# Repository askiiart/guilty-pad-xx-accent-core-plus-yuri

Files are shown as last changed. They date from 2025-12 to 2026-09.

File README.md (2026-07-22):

# Guilty Pad XX Λ Core Plus R

This is a pretty simple TKL keyboard with backlighting, an OLED, and a rotary encoder. The fancy trick is that it's designed to work with the [GUILTY PAD -GAY-](https://github.com/askiiart/guilty-pad-gay), so you can do whatever you want with it via Bluetooth. Connect them together and use the hackpad as macro key combos or something, literally anything!

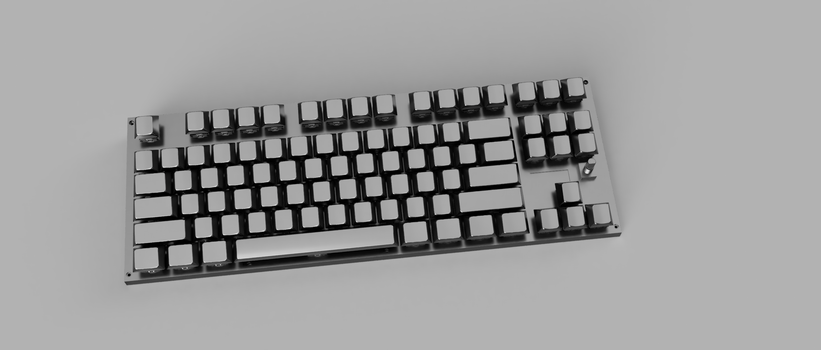
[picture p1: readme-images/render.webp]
A render of the board looking straight-ish at it


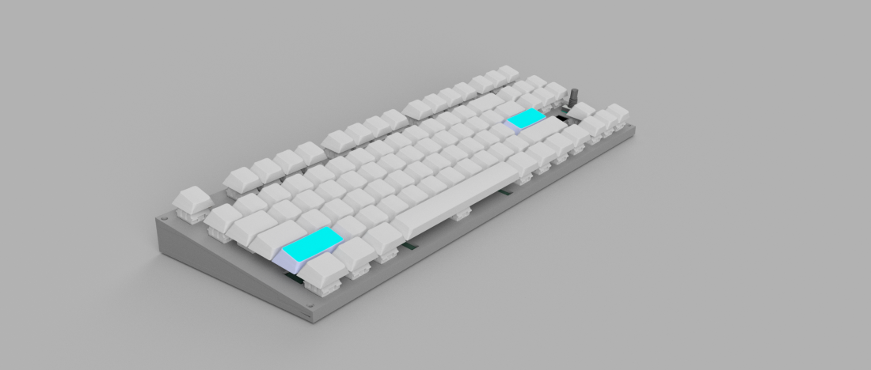
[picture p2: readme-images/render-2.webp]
A render of the board looking at it at a roughly 45 degree angle from the front-left-top side


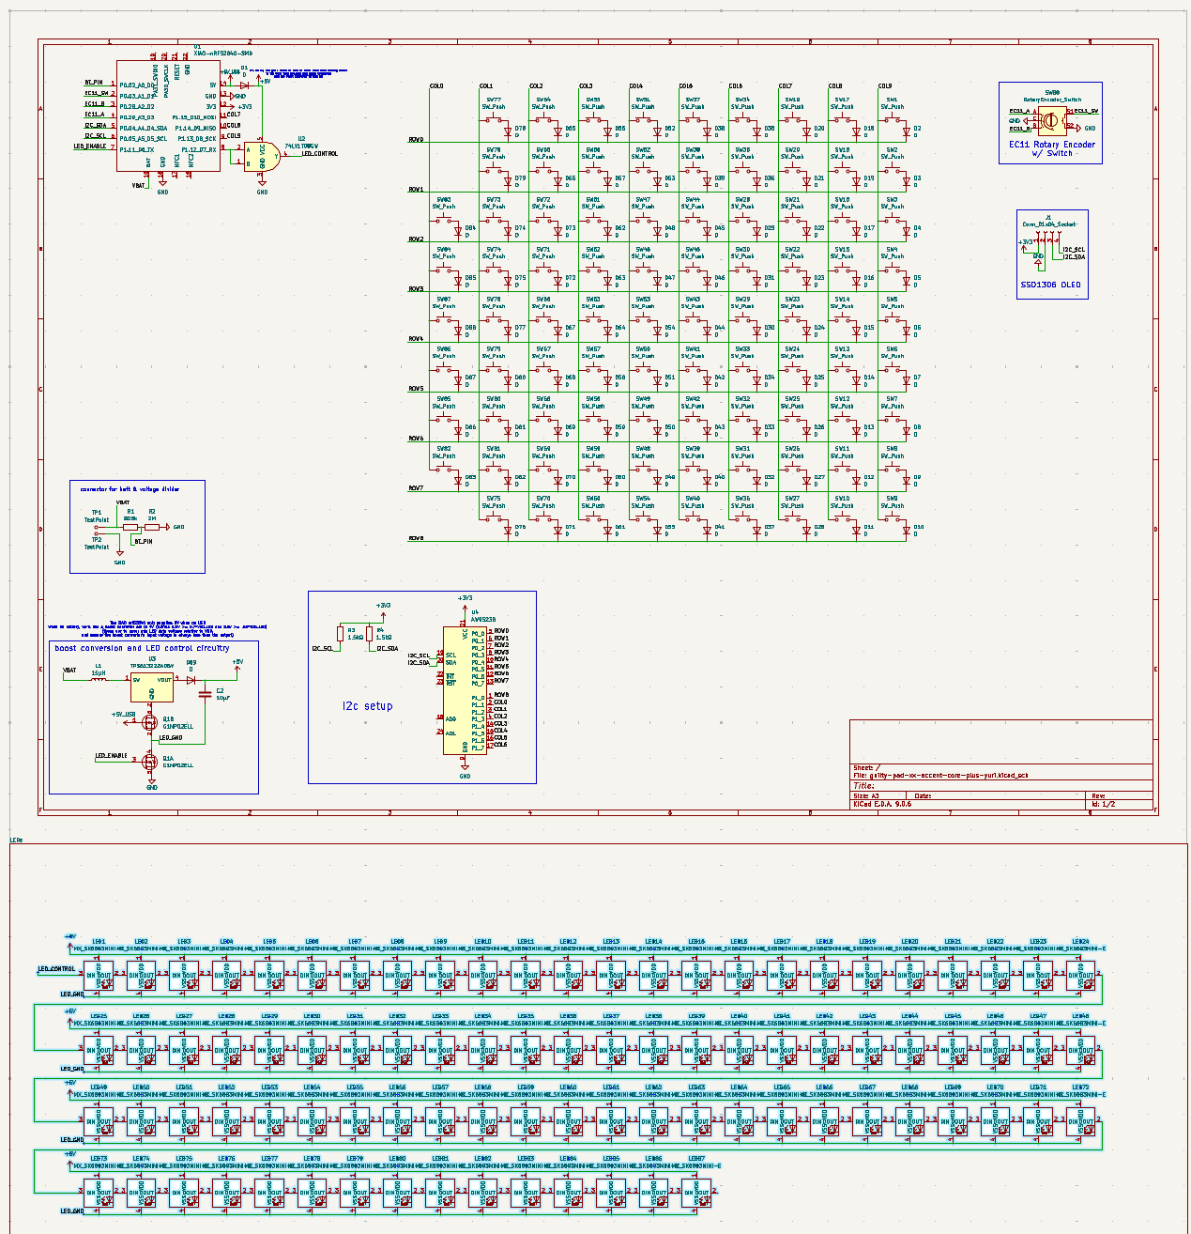
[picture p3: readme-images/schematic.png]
A screenshot of the schematic


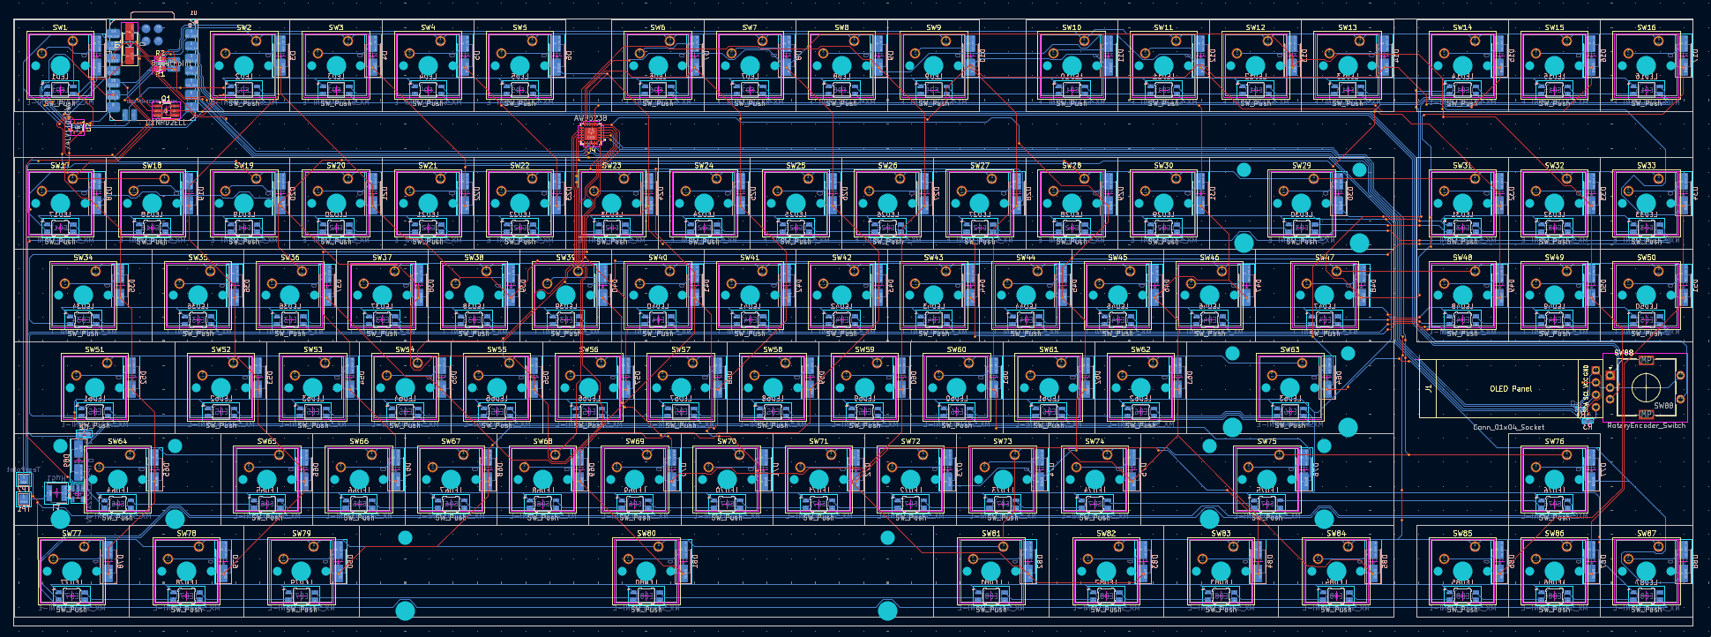
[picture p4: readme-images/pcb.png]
A screenshot of the PCB


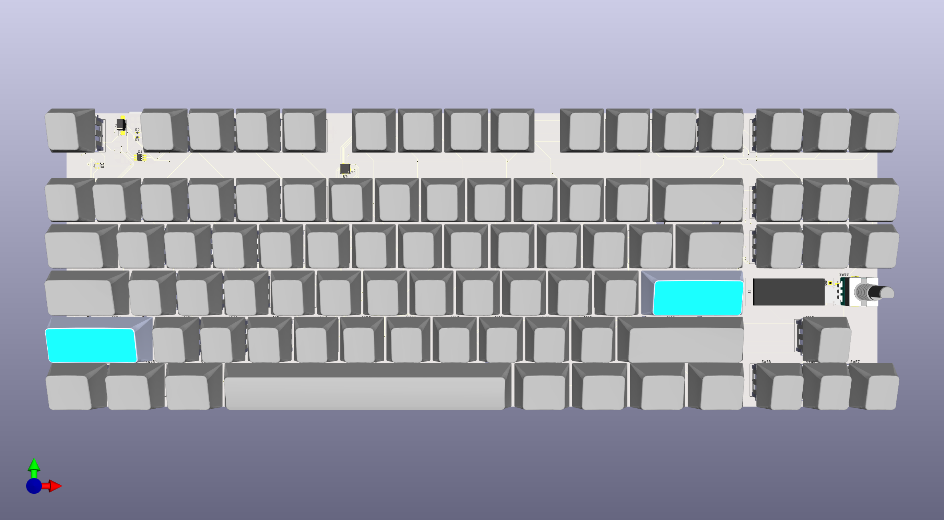
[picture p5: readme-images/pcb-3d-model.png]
A screenshot of the 3D rendering of the PCB with all components


---

The woke left made me add yuri (I actually haven't added any yet, busy doing actually useful stuff)

## Bill of Materials

| Name | Link | Unit price | Quantity needed | MOQ | Multiple | Total per item |
| --- | --- | --- | --- | --- | --- | --- |
| XIAO nrf52840 | <https://www.seeedstudio.com/Seeed-XIAO-BLE-nRF52840-p-5201.html> | 8.99 | 1 | 1 | 1 | 8.99 |
| 0402 4.7k resistors (GR0402J4K7TAG00) | <https://www.lcsc.com/product-detail/C49656853.html> | 0 | 2 | 100 | 100 | 0.04 |
| Rotary encoder w/ switch (EC11E18244A5) | <https://www.lcsc.com/product-detail/C255515.html> | 2.05 | 1 | 1 | 1 | 2.05 |
| 0402 806k resistor (SCR0402F806K) | <https://www.lcsc.com/product-detail/C3016043.html> | 0 | 1 | 100 | 100 | 0.05 |
| 0402 2M resistor (GR0402J2MTAG00) | <https://www.lcsc.com/product-detail/C49653113.html> | 0 | 1 | 100 | 100 | 0.04 |
| 0603 10uF capacitor (CL10A106MQ8NNNC) | <https://www.lcsc.com/product-detail/C1691.html> | 0 | 1 | 50  | 50 | 0.24 |
| 60x Mill-Max hotswap sockets | <https://keeb.io/products/mill-max-hotswap-sockets?variant=32377167511646> | 7.99 | 3 | 1 | 1 | 23.97 |
| 20x SK6803MINI-E (LEDs) | <https://www.aliexpress.us/item/3256807898532204.html> | 31.16 | 5 | 1 | 1 | 24.7 |
| 22 AWG wires w/ JST XH connectors | <https://www.aliexpress.us/item/3256803495901819.html> | 0.99 | 1 | 1 | 1 | 0.99 |
| Complimentary P/N channel MOSFETs (G1NP02ELL) | <https://www.lcsc.com/product-detail/C840056.html> | 0.03 | 1 | 20  | 20 | 0.66 |
| 15 uH Inductor (SLW4030S150MST) | <https://www.lcsc.com/product-detail/C206361.html> | 0.07 | 1 | 10  | 10 | 0.69 |
| 5V boost converter (H8118A40PR) | <https://www.lcsc.com/product-detail/C410998.html> | 0.13 | 1 | 5 | 5 | 0.66 |
| Diodes (1N4001) | <https://www.lcsc.com/product-detail/C2909965.html> | 0 | 89 | 50  | 50 | 0.41 |
| Level shifter (74LV1T08GW-TP) | <https://www.lcsc.com/product-detail/C42460230.html> | 0.06 | 1 | 10  | 10 | 0.57 |
| 90x MX switches (Holy Panda 55g) | <https://www.aliexpress.us/item/3256805924985540.html> | 5.49 | 1 | 1 | 1 | 5.49 |
| IO expander (AW9523BTQR) | <https://www.lcsc.com/product-detail/C148077.html> | 0.35 | 1 | 1 | 1 | 0.35 |
| Keycaps | <https://www.aliexpress.us/item/3256809006592332.html> | 0.99 | 1 | 1 | 1 | 0.99 |
| 5000mAh 307090 lipo | <https://www.aliexpress.us/item/3256809787664995.html> | $5.18 | 1 | 1 | 1 | 4.18 |
| M2 screws and heat-set inserts (10x M2x3 inserts, 6x M2x4 (5?), 4x M2xTBD) | <https://www.aliexpress.us/item/3256807644176828.html> | 0.99 | 1 | 1 | 0.99 | 0.99 |
| 0.91" 128x32 OLED | <https://www.aliexpress.us/item/3256804386173217.html> | 0.99 | 1 | 1 | 0.99 | 0.99 |
| | | | | | | |
| Component Total | | | | | | 78.05 |
| | | | | | | |
| PCB total | | | | | | 29.74 |
| Seeed studio shipping | | | | | | 5.46 |
| keeb.io shipping | | | | | | 6.37 |
| SK6803MINI-E shipping | | | | | | 6.52 |
| 5000mAh lipo shipping | | | | | | 5.41 |
| LCSC shipping & handling | | | | | | 11.71 |
| | | | | | | |
| Subtotal | | | | | | 143.25 |
| Without mill-max sockets | | | | | | 112.91 |
| | | | | | | |
| Total | | | | | | 155.07 |
| **Without mill-max sockets** | | | | | | 122.23 |

## TODO

- redo routing everything
- [crystal](https://www.lcsc.com/product-detail/C18213028.html)
  - [capacitors](https://www.lcsc.com/product-detail/C501818.html)
- [antenna](https://www.lcsc.com/product-detail/C42395593.html)
- [usb resistors](https://www.lcsc.com/product-detail/C2906874.html)
- battery management chip: [SGM40567](https://www.lcsc.com/product-detail/C5141336.html)
  - [digipot for PROG](https://www.lcsc.com/product-detail/C649485.html)
- [usb-c port](https://jlcpcb.com/partdetail/Korean_HropartsElec-TYPE_C_31_M12/C165948)
- reset button
  - [reset button?](https://www.aliexpress.us/item/3256806601702089.html)
  - [reset buttonnnnnn?](https://www.lcsc.com/product-detail/C49234121.html)
- [pmos for voltage regulators](https://www.lcsc.com/product-detail/C239037.html)
- [D4 (3A)](https://www.lcsc.com/product-detail/C97127.html)
- [D1, D2, D3, D7 (1A)](https://www.lcsc.com/product-detail/C2912031.html)
- [D5, D6 (2A)](https://www.lcsc.com/product-detail/C153761.html)
- [5V boost converter](https://www.lcsc.com/product-detail/C621881.html)

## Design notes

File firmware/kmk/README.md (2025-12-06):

Just basic firmware to get it working, not doing anything fancy since I can't test currently

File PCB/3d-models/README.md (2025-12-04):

# 3d model sources

- [XIAO nrf52840](https://www.printables.com/model/1336692-3d-model-for-seeed-studio-xiao-nrf52840)
- [SK6812MINI-E](https://grabcad.com/library/sk6812mini-e-led-1)
- [OLED](https://github.com/MichMich/KiCad-SSD1306_OLED-0.91-128x32)
- [Kailh MX switch](https://grabcad.com/library/kailh-polia-switch-cherry-mx-compatible-1)
- [IO Expander](https://kicad.github.io/packages3d/Package_DFN_QFN.html)
- [Level shifter](https://kicad.github.io/download/packages3d/Package_TO_SOT_SMD.3dshapes.7z)
- [EC11 rotary encoder](https://grabcad.com/library/rotary-encoder-17)
- [keycaps](hthttps://github.com/hineybush/CherryMX)

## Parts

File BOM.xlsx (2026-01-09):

Name | Link | Unit price | Quantity needed | MOQ | Multiple | Quantity to order | Total per item
XIAO nRF52840 | https://www.seeedstudio.com/Seeed-XIAO-BLE-nRF52840-p-5201.html | 8.99 | 1 | 1 | 1 | 1 | 8.99
0402 4.7k resistors (GR0402J4K7TAG00) | https://www.lcsc.com/product-detail/C49656853.html | 0.0004 | 2 | 100 | 100 | 100 | 0.04
Rotary encoder w/ switch (EC11E18244A5) | https://www.lcsc.com/product-detail/C255515.html | 2.05 | 1 | 1 | 1 | 1 | 2.05
0402 806k resistor (SCR0402F806K) | https://www.lcsc.com/product-detail/C3016043.html | 0.0005 | 1 | 100 | 100 | 100 | 0.05
0402 2M resistor (GR0402J2MTAG00) | https://www.lcsc.com/product-detail/C49653113.html | 0.0004 | 1 | 100 | 100 | 100 | 0.04
0603 10uF capacitor (CL10A106MQ8NNNC) | https://www.lcsc.com/product-detail/C1691.html | 0.0048 | 1 | 50 | 50 | 50 | 0.24
Gateron/Outemu 90x hotswap sockets | https://www.aliexpress.com/item/3256802450835694.html?mp=1 | 0.99 | 1 | 1 | 1 | 1 | 0.99
LEDs (SK6803MINI-E) | https://www.lcsc.com/product-detail/C5242955.html | 0.0656 | 90 | 5 | 5 | 90 | 5.904
22 AWG wires w/ JST XH connectors | https://www.aliexpress.us/item/3256803495901819.html | 0.99 | 1 | 1 | 1 | 1 | 0.99
Complimentary P/N channel MOSFETs (G1NP02ELL) | https://www.lcsc.com/product-detail/C840056.html | 0.0332 | 1 | 20 | 20 | 20 | 0.664
15 uH Inductor (SLW4030S150MST) | https://www.lcsc.com/product-detail/C206361.html | 0.039 | 1 | 10 | 10 | 10 | 0.39
5V boost converter (TPS613222ADBVR) | https://www.lcsc.com/product-detail/C2071163.html | 0.1487 | 1 | 5 | 5 | 5 | 0.7435
Diodes (1N4148) | https://www.lcsc.com/product-detail/C2904852.html?s_z=n_1n4148 | 0.004 | 89 | 100 | 100 | 100 | 0.4
Level shifter (74LV1T08GW-TP) | https://www.lcsc.com/product-detail/C42460230.html | 0.057 | 2 | 10 | 10 | 10 | 0.57
MX switches | Any | 0 | 87 | 1 | 1 | 87 | 0
IO expander (PCA9555PW) | https://www.lcsc.com/product-detail/C42420607.html | 0.2831 | 1 | 1 | 1 | 1 | 0.2831
Keycaps | https://www.aliexpress.com/item/3256807135386098.html?mp=1 | 7.88 | 1 | 1 | 1 | 1 | 7.88
5000mAh lipo | https://www.aliexpress.com/item/3256808773650739.html?mp=1 | 8.03 | 1 | 1 | 1 | 1 | 8.03
M2 screws and heat-set inserts (10x M2x3 inserts, 6x M2x4 (5?), 4x M2xTBD) | https://www.aliexpress.us/item/3256807644176828.html | 5.09 | 1 | 1 | 1 | 1 | 5.09
0.91" 128x32 OLED | https://www.aliexpress.us/item/3256804386173217.html | 2.02 | 1 | 1 | 1 | 1 | 2.02
Component Total |  |  |  |  |  |  | 45.3646
PCB total |  |  |  |  |  |  | 39.13
Seeed studio shipping |  |  |  |  |  |  | 5.46
5000mAh lipo shipping |  |  |  |  |  |  | 5.43
LCSC shipping & handling |  |  |  |  |  |  | 11.71
Subtotal |  |  |  |  |  |  | 107.0946
Total |  |  |  |  |  |  | 115.9299045

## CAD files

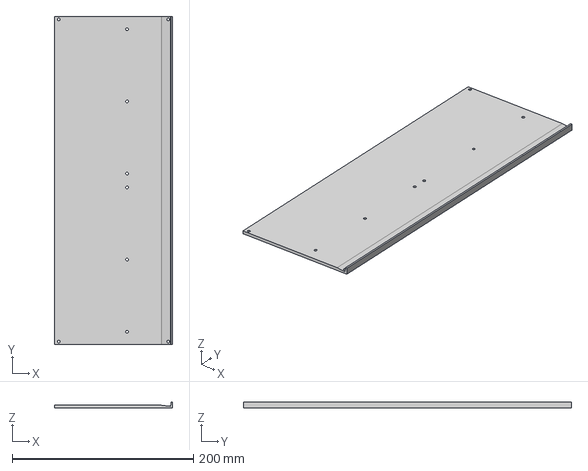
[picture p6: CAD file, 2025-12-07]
CAD/case-bottom.step
130.5 x 362.2 x 6.95 mm

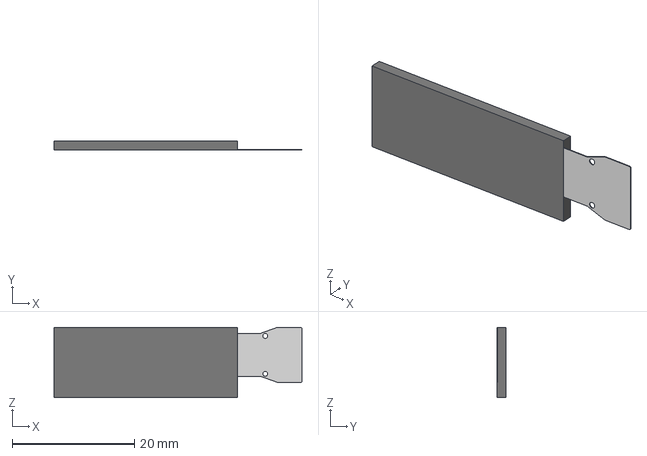
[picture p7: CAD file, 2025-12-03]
PCB/3d-models/SSD1306_OLED-0.91-128x32.step
40.5 x 1.45 x 11.5 mm

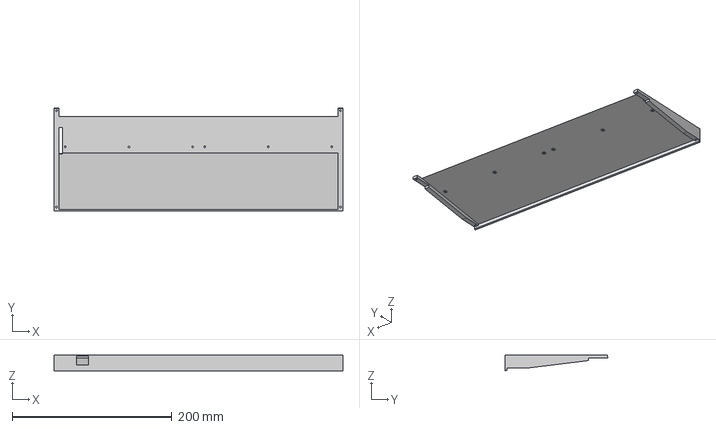
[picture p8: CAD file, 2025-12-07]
CAD/case-middle.step
362.2 x 128.9 x 19.6 mm

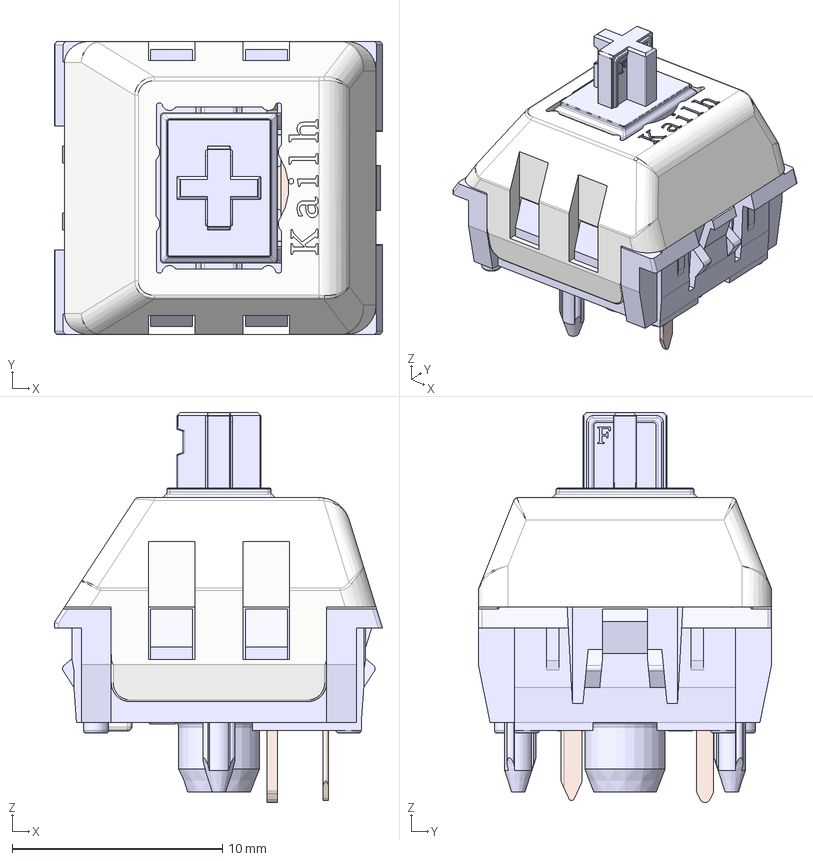
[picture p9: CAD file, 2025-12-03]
PCB/3d-models/Kailh Polia.step
15.6 x 14.0 x 18.5 mm
Housing
ThickContact
SpringContact
Stem
Lid

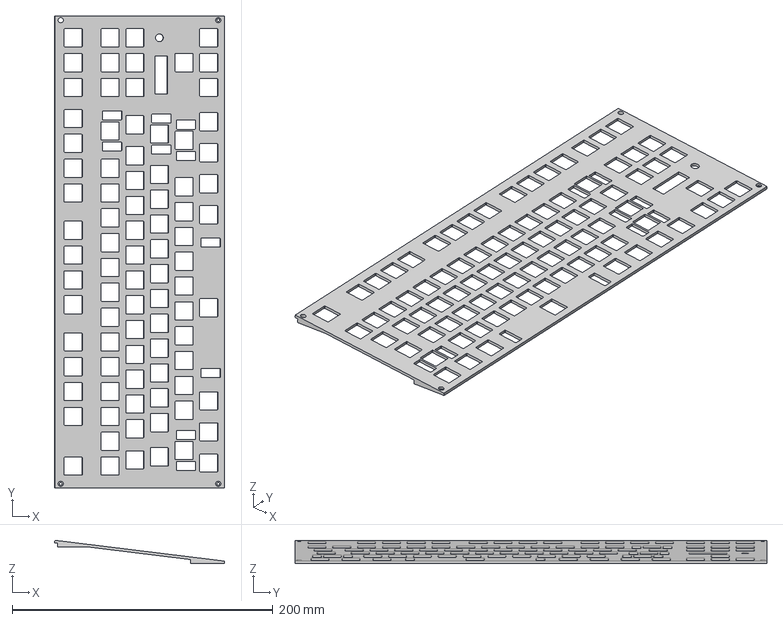
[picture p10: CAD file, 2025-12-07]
CAD/case-top.step
130.5 x 362.2 x 18.0 mm

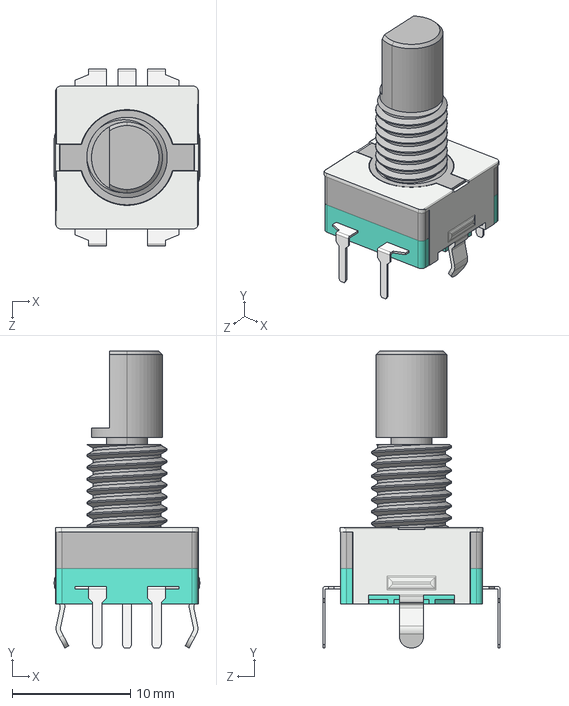
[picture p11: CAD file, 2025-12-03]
PCB/3d-models/ec11.step
12.3 x 25.1 x 15.0 mm

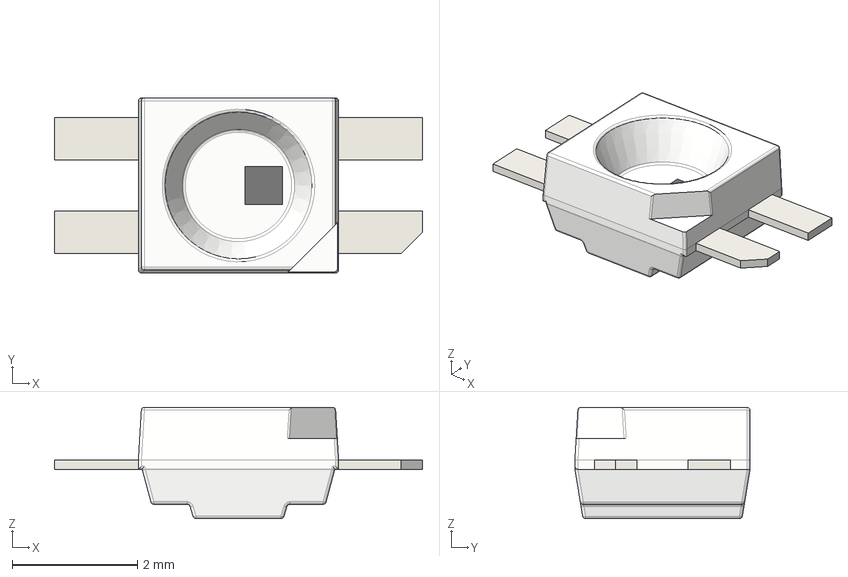
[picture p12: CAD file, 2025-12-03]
PCB/3d-models/LED_SK6812MINI-E.step
5.88 x 2.80 x 1.78 mm

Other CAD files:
CAD/case-bottom.f3d
CAD/case-middle.f3d
CAD/case-top.f3d

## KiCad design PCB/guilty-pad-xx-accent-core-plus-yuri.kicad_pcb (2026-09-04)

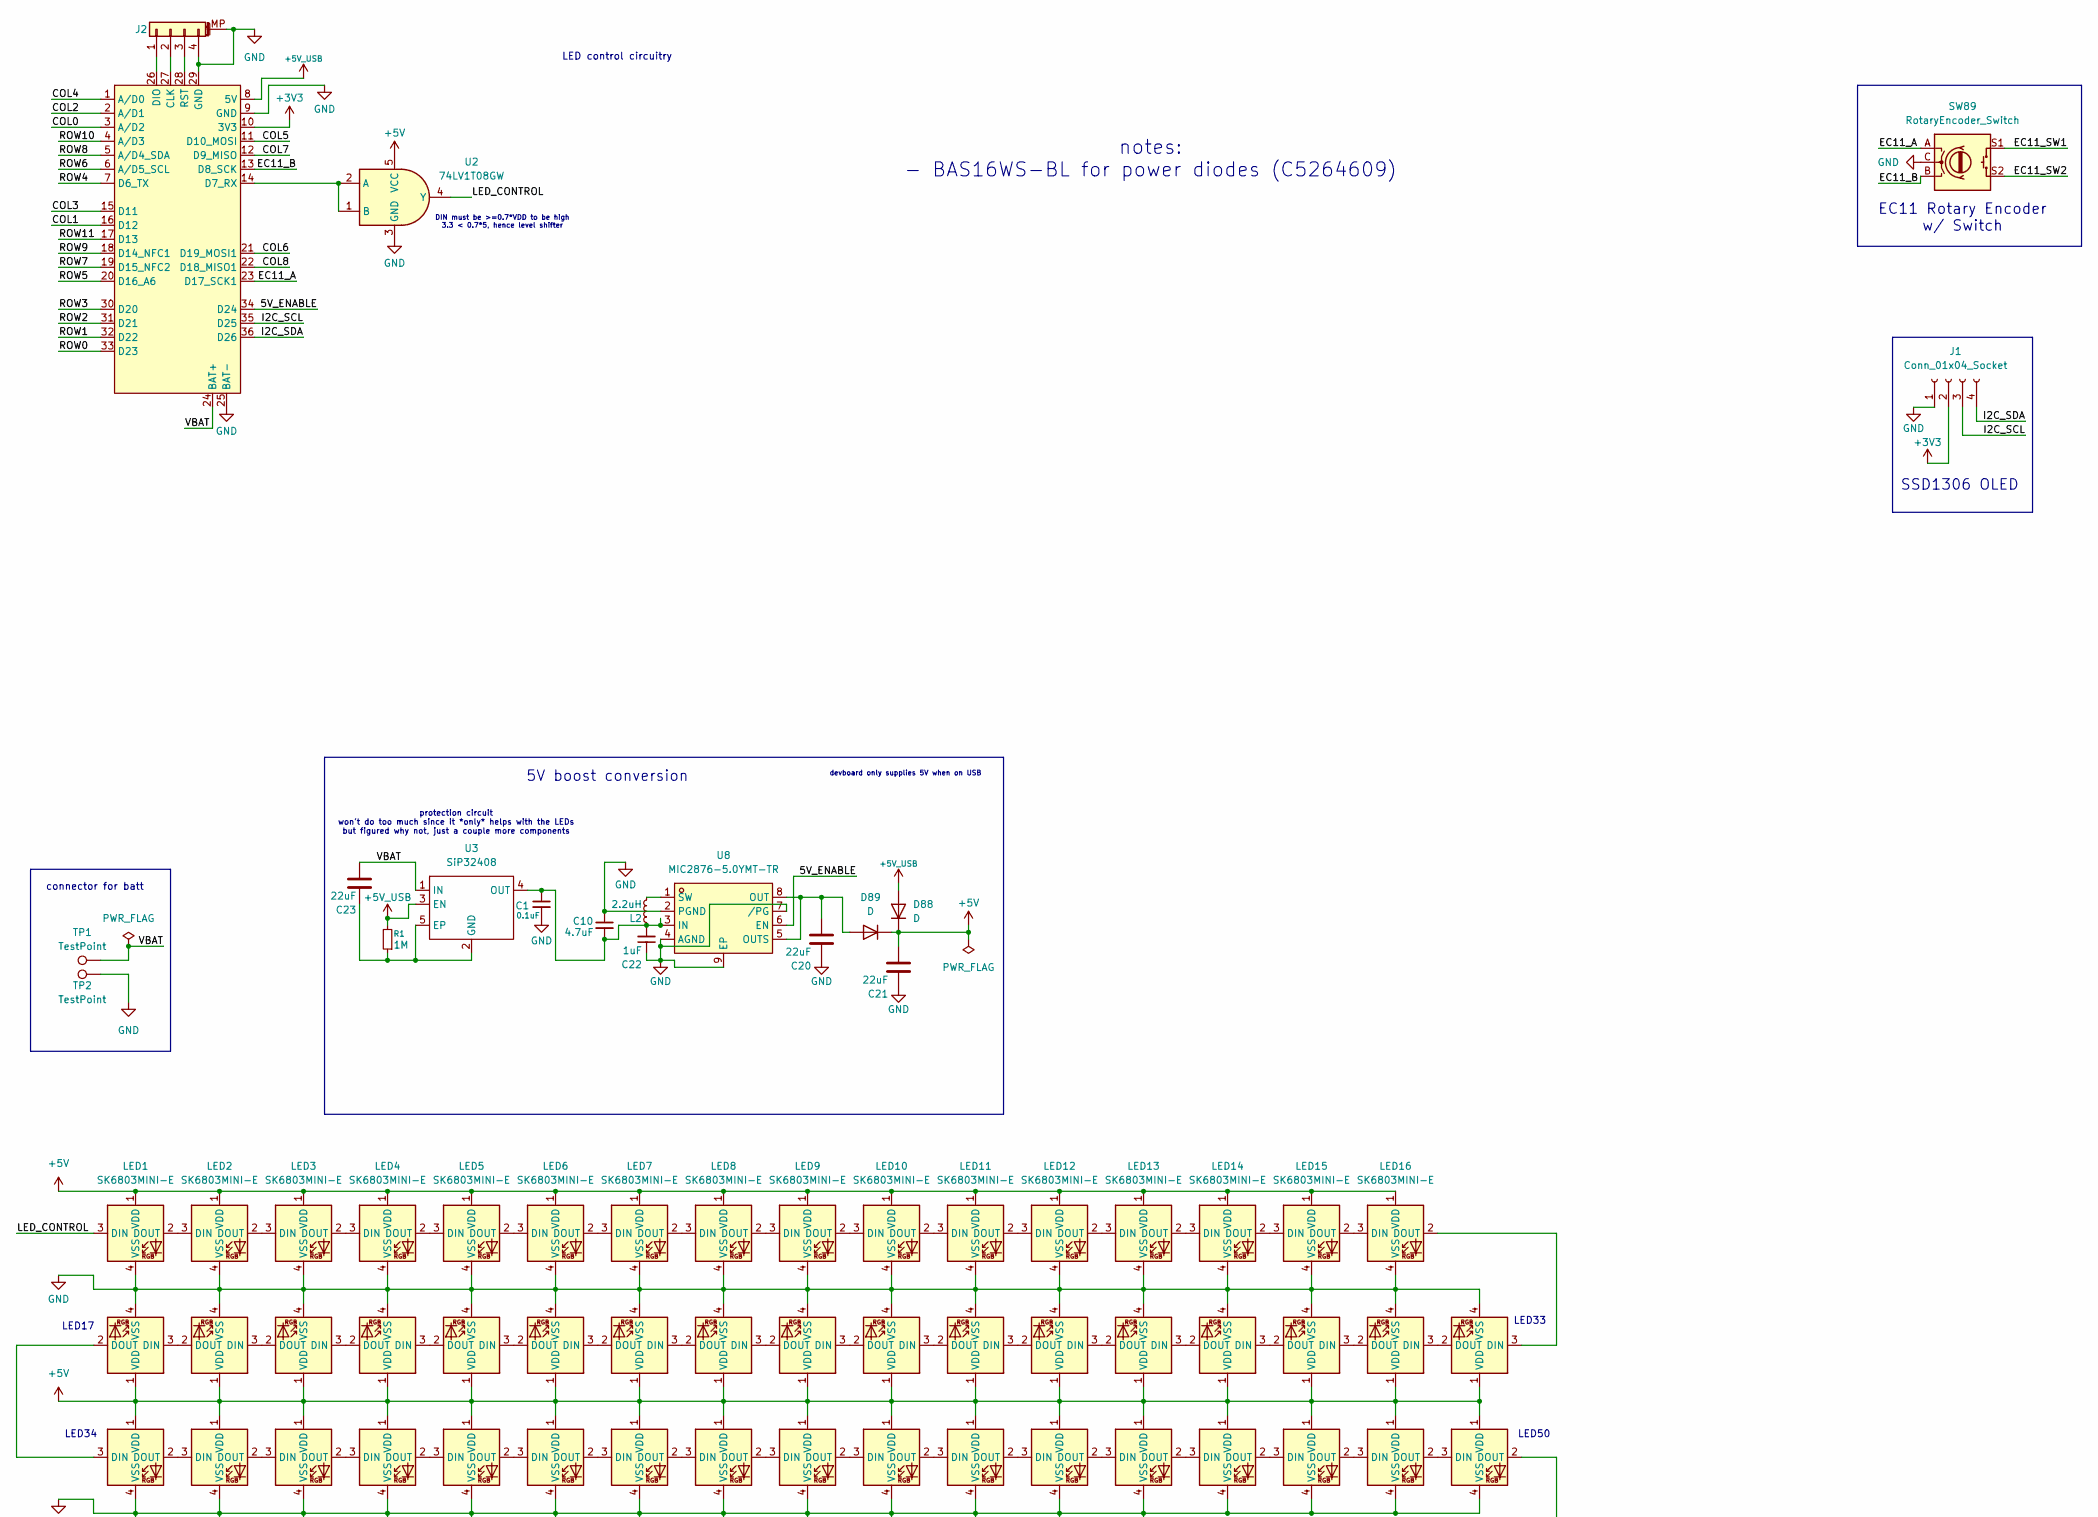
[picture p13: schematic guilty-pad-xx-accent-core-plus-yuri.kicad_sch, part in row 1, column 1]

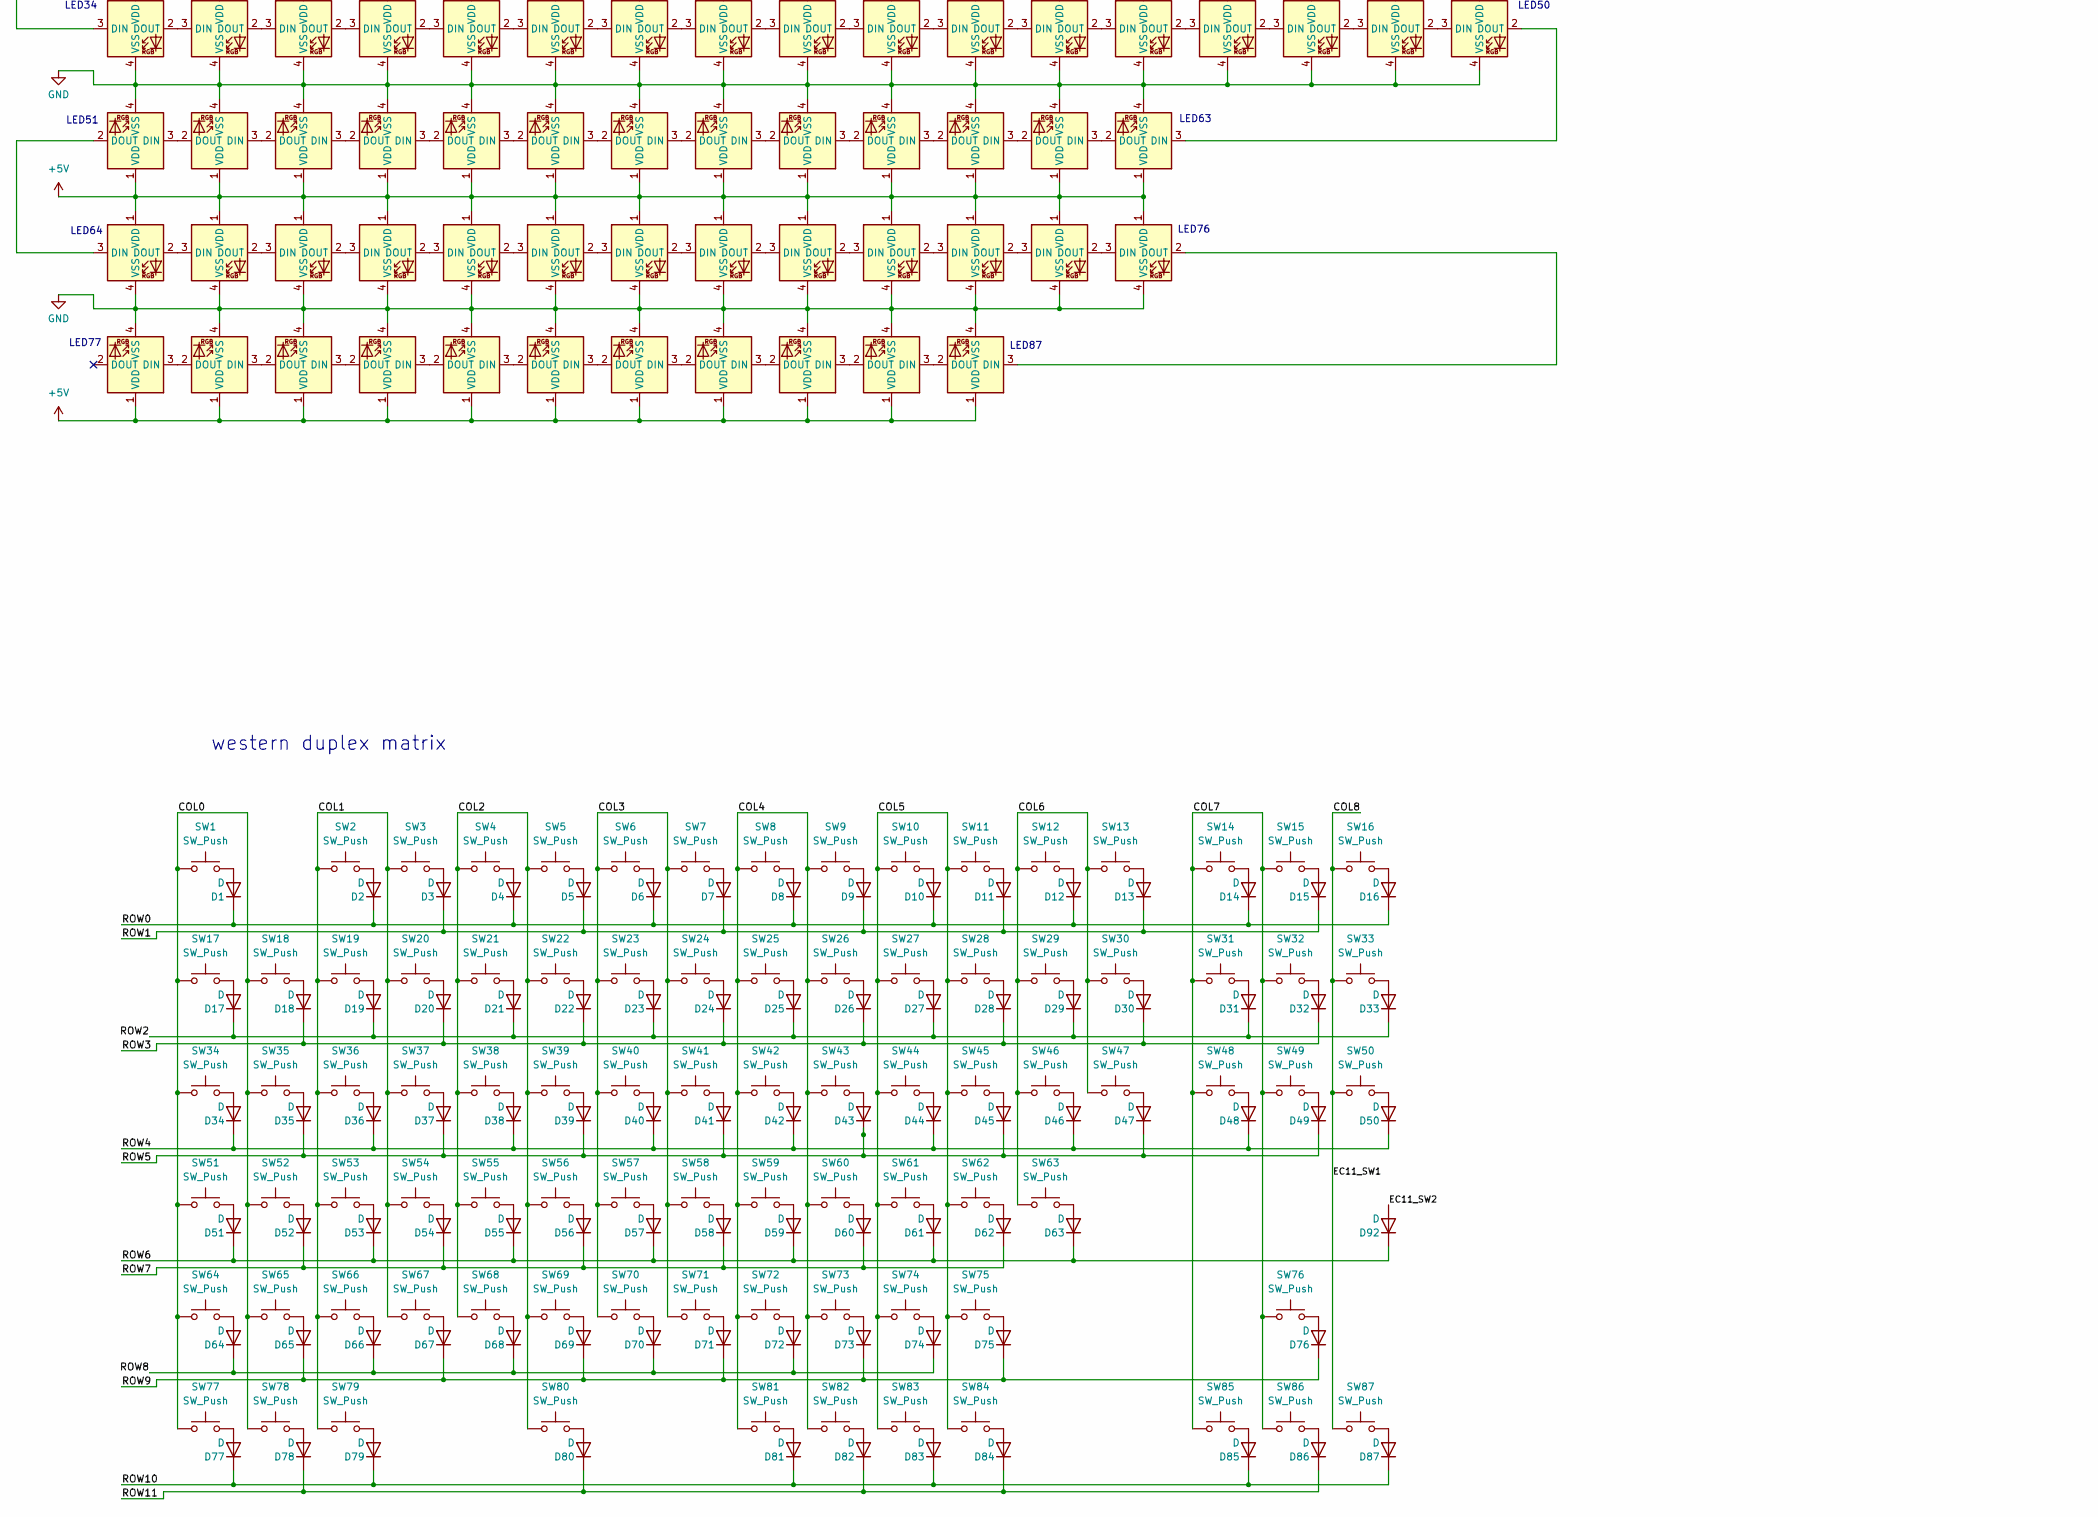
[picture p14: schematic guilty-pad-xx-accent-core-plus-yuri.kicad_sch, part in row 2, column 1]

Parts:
C1: 0.1uF; C_0603_1608Metric
C10: 4.7uF; C_0603_1608Metric
C20, C21, C23: 22uF; C_0603_1608Metric
C22: 1uF; C_0603_1608Metric
D1, D2, D3, D4, D5, D6, D7, D8, D9, D10, D11, D12, D13, D14, D15, D16, D17, D18, D19, D20, D21, D22, D23, D24, D25, D26, D27, D28, D29, D30, D31, D32, D33, D34, D35, D36, D37, D38, D39, D40, D41, D42, D43, D44, D45, D46, D47, D48, D49, D50, D51, D52, D53, D54, D55, D56, D57, D58, D59, D60, D61, D62, D63, D64, D65, D66, D67, D68, D69, D70, D71, D72, D73, D74, D75, D76, D77, D78, D79, D80, D81, D82, D83, D84, D85, D86, D87, D88, D89, D92: D; D_SOD-323_HandSoldering
J1: Conn_01x04_Socket; SSD1306-0.91-OLED-4pin-128x32
J2: Conn_01x04_MountingPin; JST_SH_BM04B-SRSS-TB_1x04-1MP_P1.00mm_Vertical
L2: 2.2uH; L_0805_2012Metric
LED1, LED2, LED3, LED4, LED5, LED6, LED7, LED8, LED9, LED10, LED11, LED12, LED13, LED14, LED15, LED16, LED17, LED18, LED19, LED20, LED21, LED22, LED23, LED24, LED25, LED26, LED27, LED28, LED29, LED30, LED31, LED32, LED33, LED34, LED35, LED36, LED37, LED38, LED39, LED40, LED41, LED42, LED43, LED44, LED45, LED46, LED47, LED48, LED49, LED50, LED51, LED52, LED53, LED54, LED55, LED56, LED57, LED58, LED59, LED60, LED61, LED62, LED63, LED64, LED65, LED66, LED67, LED68, LED69, LED70, LED71, LED72, LED73, LED74, LED75, LED76, LED77, LED78, LED79, LED80, LED81, LED82, LED83, LED84, LED85, LED86, LED87: SK6803MINI-E; LED_6028R
R1: 1M; R_0603_1608Metric
SW1, SW2, SW3, SW4, SW5, SW6, SW7, SW8, SW9, SW10, SW11, SW12, SW13, SW14, SW15, SW16, SW17, SW18, SW19, SW20, SW21, SW22, SW23, SW24, SW25, SW26, SW27, SW28, SW29, SW30, SW31, SW32, SW33, SW35, SW36, SW37, SW38, SW39, SW40, SW41, SW42, SW43, SW44, SW45, SW46, SW48, SW49, SW50, SW52, SW53, SW54, SW55, SW56, SW57, SW58, SW59, SW60, SW61, SW62, SW63, SW64, SW65, SW66, SW67, SW68, SW69, SW70, SW71, SW72, SW73, SW74, SW75, SW76, SW80, SW85, SW86, SW87: SW_Push; SW_MX_HS_CPG151101S11_1u
SW34, SW47: SW_Push; SW_MX_HS_CPG151101S11_1.5u
SW51: SW_Push; SW_MX_HS_CPG151101S11_1.75u
SW77, SW78, SW79, SW81, SW82, SW83, SW84: SW_Push; SW_MX_HS_CPG151101S11_1.25u
SW89: RotaryEncoder_Switch; RotaryEncoder_Alps_EC11E-Switch_Vertical_H20mm
TP1, TP2: TestPoint; TestPoint_Pad_2.0x2.0mm
U1: Guilty Devboard Xrd; Guilty Devboard Xrd - SMD
U2: 74LV1T08GW; SOT-353_SC-70-5
U3: SiP32408; UDFN-4-1EP_1.2x1.6mm_P0.5mm_EP0.86x0.5mm
U8: MIC2876-5.0YMT-TR; UDFN-8_L2.0-W2.0-P0.50-BL-EP; LCSC Part C621881

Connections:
+3V3: J1.2, U1.10 (3V3)
+5V: C21.2, D88.1 (K), D89.1 (K), LED1.1 (VDD), LED2.1 (VDD), LED3.1 (VDD), LED4.1 (VDD), LED5.1 (VDD), LED6.1 (VDD), LED7.1 (VDD), LED8.1 (VDD), LED9.1 (VDD), LED10.1 (VDD), LED11.1 (VDD), LED12.1 (VDD), LED13.1 (VDD), LED14.1 (VDD), LED15.1 (VDD), LED16.1 (VDD), LED17.1 (VDD), LED18.1 (VDD), LED19.1 (VDD), LED20.1 (VDD), LED21.1 (VDD), LED22.1 (VDD), LED23.1 (VDD), LED24.1 (VDD), LED25.1 (VDD), LED26.1 (VDD), LED27.1 (VDD), LED28.1 (VDD), LED29.1 (VDD), LED30.1 (VDD), LED31.1 (VDD), LED32.1 (VDD), LED33.1 (VDD), LED34.1 (VDD), LED35.1 (VDD), LED36.1 (VDD), LED37.1 (VDD), LED38.1 (VDD), LED39.1 (VDD), LED40.1 (VDD), LED41.1 (VDD), LED42.1 (VDD), LED43.1 (VDD), LED44.1 (VDD), LED45.1 (VDD), LED46.1 (VDD), LED47.1 (VDD), LED48.1 (VDD), LED49.1 (VDD), LED50.1 (VDD), LED51.1 (VDD), LED52.1 (VDD), LED53.1 (VDD), LED54.1 (VDD), LED55.1 (VDD), LED56.1 (VDD), LED57.1 (VDD), LED58.1 (VDD), LED59.1 (VDD), LED60.1 (VDD), LED61.1 (VDD), LED62.1 (VDD), LED63.1 (VDD), LED64.1 (VDD), LED65.1 (VDD), LED66.1 (VDD), LED67.1 (VDD), LED68.1 (VDD), LED69.1 (VDD), LED70.1 (VDD), LED71.1 (VDD), LED72.1 (VDD), LED73.1 (VDD), LED74.1 (VDD), LED75.1 (VDD), LED76.1 (VDD), LED77.1 (VDD), LED78.1 (VDD), LED79.1 (VDD), LED80.1 (VDD), LED81.1 (VDD), LED82.1 (VDD), LED83.1 (VDD), LED84.1 (VDD), LED85.1 (VDD), LED86.1 (VDD), LED87.1 (VDD), U2.5 (VCC)
+5V_USB: D88.2 (A), R1.2, U1.8 (5V), U3.3 (EN)
/5V_ENABLE: U1.34 (D24), U8.6 (EN)
/COL0: SW1.1, SW17.1, SW18.1, SW34.1, SW35.1, SW51.1, SW52.1, SW64.1, SW65.1, SW77.1, SW78.1, U1.3 (A/D2)
/COL1: SW2.1, SW3.1, SW19.1, SW20.1, SW36.1, SW37.1, SW53.1, SW54.1, SW66.1, SW67.1, SW79.1, U1.16 (D12)
/COL2: SW4.1, SW5.1, SW21.1, SW22.1, SW38.1, SW39.1, SW55.1, SW56.1, SW68.1, SW69.1, SW80.1, U1.2 (A/D1)
/COL3: SW6.1, SW7.1, SW23.1, SW24.1, SW40.1, SW41.1, SW57.1, SW58.1, SW70.1, SW71.1, U1.15 (D11)
/COL4: SW8.1, SW9.1, SW25.1, SW26.1, SW42.1, SW43.1, SW59.1, SW60.1, SW72.1, SW73.1, SW81.1, SW82.1, U1.1 (A/D0)
/COL5: SW10.1, SW11.1, SW27.1, SW28.1, SW44.1, SW45.1, SW61.1, SW62.1, SW74.1, SW75.1, SW83.1, SW84.1, U1.11 (D10_MOSI)
/COL6: SW12.1, SW13.1, SW29.1, SW30.1, SW46.1, SW47.1, SW63.1, U1.21 (D19_MOSI1)
/COL7: SW14.1, SW15.1, SW31.1, SW32.1, SW48.1, SW49.1, SW76.1, SW85.1, SW86.1, U1.12 (D9_MISO)
/COL8: SW16.1, SW33.1, SW50.1, SW87.1, SW89.S1, U1.22 (D18_MISO1)
/EC11_A: SW89.A, U1.23 (D17_SCK1)
/EC11_B: SW89.B, U1.13 (D8_SCK)
/EC11_SW2: D92.2 (A), SW89.S2
/I2C_SCL: J1.3, U1.35 (D25)
/I2C_SDA: J1.4, U1.36 (D26)
/LED_CONTROL: LED1.3 (DIN), U2.4 (Y)
/ROW0: D1.1 (K), D2.1 (K), D4.1 (K), D6.1 (K), D8.1 (K), D10.1 (K), D12.1 (K), D14.1 (K), D16.1 (K), U1.33 (D23)
/ROW1: D3.1 (K), D5.1 (K), D7.1 (K), D9.1 (K), D11.1 (K), D13.1 (K), D15.1 (K), U1.32 (D22)
/ROW2: D17.1 (K), D19.1 (K), D21.1 (K), D23.1 (K), D25.1 (K), D27.1 (K), D29.1 (K), D31.1 (K), D33.1 (K), U1.31 (D21)
/ROW3: D18.1 (K), D20.1 (K), D22.1 (K), D24.1 (K), D26.1 (K), D28.1 (K), D30.1 (K), D32.1 (K), U1.30 (D20)
/ROW4: D34.1 (K), D36.1 (K), D38.1 (K), D40.1 (K), D42.1 (K), D44.1 (K), D46.1 (K), D48.1 (K), D50.1 (K), U1.7 (D6_TX)
/ROW5: D35.1 (K), D37.1 (K), D39.1 (K), D41.1 (K), D43.1 (K), D45.1 (K), D47.1 (K), D49.1 (K), U1.20 (D16_A6)
/ROW6: D51.1 (K), D53.1 (K), D55.1 (K), D57.1 (K), D59.1 (K), D61.1 (K), D63.1 (K), D92.1 (K), U1.6 (A/D5_SCL)
/ROW7: D52.1 (K), D54.1 (K), D56.1 (K), D58.1 (K), D60.1 (K), D62.1 (K), U1.19 (D15_NFC2)
/ROW8: D64.1 (K), D66.1 (K), D68.1 (K), D70.1 (K), D72.1 (K), D74.1 (K), U1.5 (A/D4_SDA)
/ROW9: D65.1 (K), D67.1 (K), D69.1 (K), D71.1 (K), D73.1 (K), D75.1 (K), D76.1 (K), U1.18 (D14_NFC1)
/ROW10: D77.1 (K), D79.1 (K), D81.1 (K), D83.1 (K), D85.1 (K), D87.1 (K), U1.4 (A/D3)
/ROW11: D78.1 (K), D80.1 (K), D82.1 (K), D84.1 (K), D86.1 (K), U1.17 (D13)
/VBAT: C23.2, TP1.1 (1_1), U1.24 (BAT+), U3.1 (IN)
unnamed: D1.2 (A), SW1.2
unnamed: D2.2 (A), SW2.2
unnamed: D3.2 (A), SW3.2
unnamed: D4.2 (A), SW4.2
unnamed: D5.2 (A), SW5.2
unnamed: D6.2 (A), SW6.2
unnamed: D7.2 (A), SW7.2
unnamed: D8.2 (A), SW8.2
unnamed: D9.2 (A), SW9.2
unnamed: D10.2 (A), SW10.2
unnamed: D11.2 (A), SW11.2
unnamed: D12.2 (A), SW12.2
unnamed: D13.2 (A), SW13.2
unnamed: D14.2 (A), SW14.2
unnamed: D15.2 (A), SW15.2
unnamed: D16.2 (A), SW16.2
unnamed: D17.2 (A), SW17.2
unnamed: D18.2 (A), SW18.2
unnamed: D19.2 (A), SW19.2
unnamed: D20.2 (A), SW20.2
unnamed: D21.2 (A), SW21.2
unnamed: D22.2 (A), SW22.2
unnamed: D23.2 (A), SW23.2
unnamed: D24.2 (A), SW24.2
unnamed: D25.2 (A), SW25.2
unnamed: D26.2 (A), SW26.2
unnamed: D27.2 (A), SW27.2
unnamed: D28.2 (A), SW28.2
unnamed: D29.2 (A), SW29.2
unnamed: D30.2 (A), SW30.2
unnamed: D31.2 (A), SW31.2
unnamed: D32.2 (A), SW32.2
unnamed: D33.2 (A), SW33.2
unnamed: D34.2 (A), SW34.2
unnamed: D35.2 (A), SW35.2
unnamed: D36.2 (A), SW36.2
unnamed: D37.2 (A), SW37.2
unnamed: D38.2 (A), SW38.2
unnamed: D39.2 (A), SW39.2
unnamed: D40.2 (A), SW40.2
unnamed: D41.2 (A), SW41.2
unnamed: D42.2 (A), SW42.2
unnamed: D43.2 (A), SW43.2
unnamed: D44.2 (A), SW44.2
unnamed: D45.2 (A), SW45.2
unnamed: D46.2 (A), SW46.2
unnamed: D47.2 (A), SW47.2
unnamed: D48.2 (A), SW48.2
unnamed: D49.2 (A), SW49.2
unnamed: D50.2 (A), SW50.2
unnamed: D51.2 (A), SW51.2
unnamed: D52.2 (A), SW52.2
unnamed: D53.2 (A), SW53.2
unnamed: D54.2 (A), SW54.2
unnamed: D55.2 (A), SW55.2
unnamed: D56.2 (A), SW56.2
unnamed: D57.2 (A), SW57.2
unnamed: D58.2 (A), SW58.2
unnamed: D59.2 (A), SW59.2
unnamed: D60.2 (A), SW60.2
unnamed: D61.2 (A), SW61.2
unnamed: D62.2 (A), SW62.2
unnamed: D63.2 (A), SW63.2
unnamed: D64.2 (A), SW64.2
unnamed: D65.2 (A), SW65.2
unnamed: D66.2 (A), SW66.2
unnamed: D67.2 (A), SW67.2
unnamed: D68.2 (A), SW68.2
unnamed: D69.2 (A), SW69.2
unnamed: D70.2 (A), SW70.2
unnamed: D71.2 (A), SW71.2
unnamed: D72.2 (A), SW72.2
unnamed: D73.2 (A), SW73.2
unnamed: D74.2 (A), SW74.2
unnamed: D75.2 (A), SW75.2
unnamed: D76.2 (A), SW76.2
unnamed: D77.2 (A), SW77.2
unnamed: D78.2 (A), SW78.2
unnamed: D79.2 (A), SW79.2
unnamed: D80.2 (A), SW80.2
unnamed: D81.2 (A), SW81.2
unnamed: D82.2 (A), SW82.2
unnamed: D83.2 (A), SW83.2
unnamed: D84.2 (A), SW84.2
unnamed: D85.2 (A), SW85.2
unnamed: D86.2 (A), SW86.2
unnamed: D87.2 (A), SW87.2
unnamed: C20.2, D89.2 (A), U8.5 (OUTS), U8.8 (OUT)
unnamed: J2.1, U1.26 (DIO)
unnamed: J2.2, U1.27 (CLK)
unnamed: J2.3, U1.28 (RST)
unnamed: LED1.2 (DOUT), LED2.3 (DIN)
unnamed: LED2.2 (DOUT), LED3.3 (DIN)
unnamed: LED3.2 (DOUT), LED4.3 (DIN)
unnamed: LED4.2 (DOUT), LED5.3 (DIN)
unnamed: LED5.2 (DOUT), LED6.3 (DIN)
unnamed: LED6.2 (DOUT), LED7.3 (DIN)
unnamed: LED7.2 (DOUT), LED8.3 (DIN)
unnamed: LED8.2 (DOUT), LED9.3 (DIN)
unnamed: LED9.2 (DOUT), LED10.3 (DIN)
unnamed: LED10.2 (DOUT), LED11.3 (DIN)
unnamed: LED11.2 (DOUT), LED12.3 (DIN)
unnamed: LED12.2 (DOUT), LED13.3 (DIN)
unnamed: LED13.2 (DOUT), LED14.3 (DIN)
unnamed: LED14.2 (DOUT), LED15.3 (DIN)
unnamed: LED15.2 (DOUT), LED16.3 (DIN)
unnamed: LED16.2 (DOUT), LED33.3 (DIN)
unnamed: LED17.3 (DIN), LED18.2 (DOUT)
unnamed: LED17.2 (DOUT), LED34.3 (DIN)
unnamed: LED18.3 (DIN), LED19.2 (DOUT)
unnamed: LED19.3 (DIN), LED20.2 (DOUT)
unnamed: LED20.3 (DIN), LED21.2 (DOUT)
unnamed: LED21.3 (DIN), LED22.2 (DOUT)
unnamed: LED22.3 (DIN), LED23.2 (DOUT)
unnamed: LED23.3 (DIN), LED24.2 (DOUT)
unnamed: LED24.3 (DIN), LED25.2 (DOUT)
unnamed: LED25.3 (DIN), LED26.2 (DOUT)
unnamed: LED26.3 (DIN), LED27.2 (DOUT)
unnamed: LED27.3 (DIN), LED28.2 (DOUT)
unnamed: LED28.3 (DIN), LED29.2 (DOUT)
unnamed: LED29.3 (DIN), LED30.2 (DOUT)
unnamed: LED30.3 (DIN), LED31.2 (DOUT)
unnamed: LED31.3 (DIN), LED32.2 (DOUT)
unnamed: LED32.3 (DIN), LED33.2 (DOUT)
unnamed: LED34.2 (DOUT), LED35.3 (DIN)
unnamed: LED35.2 (DOUT), LED36.3 (DIN)
unnamed: LED36.2 (DOUT), LED37.3 (DIN)
unnamed: LED37.2 (DOUT), LED38.3 (DIN)
unnamed: LED38.2 (DOUT), LED39.3 (DIN)
unnamed: LED39.2 (DOUT), LED40.3 (DIN)
unnamed: LED40.2 (DOUT), LED41.3 (DIN)
unnamed: LED41.2 (DOUT), LED42.3 (DIN)
unnamed: LED42.2 (DOUT), LED43.3 (DIN)
unnamed: LED43.2 (DOUT), LED44.3 (DIN)
unnamed: LED44.2 (DOUT), LED45.3 (DIN)
unnamed: LED45.2 (DOUT), LED46.3 (DIN)
unnamed: LED46.2 (DOUT), LED47.3 (DIN)
unnamed: LED47.2 (DOUT), LED48.3 (DIN)
unnamed: LED48.2 (DOUT), LED49.3 (DIN)
unnamed: LED49.2 (DOUT), LED50.3 (DIN)
unnamed: LED50.2 (DOUT), LED63.3 (DIN)
unnamed: LED51.3 (DIN), LED52.2 (DOUT)
unnamed: LED51.2 (DOUT), LED64.3 (DIN)
unnamed: LED52.3 (DIN), LED53.2 (DOUT)
unnamed: LED53.3 (DIN), LED54.2 (DOUT)
unnamed: LED54.3 (DIN), LED55.2 (DOUT)
unnamed: LED55.3 (DIN), LED56.2 (DOUT)
unnamed: LED56.3 (DIN), LED57.2 (DOUT)
unnamed: LED57.3 (DIN), LED58.2 (DOUT)
unnamed: LED58.3 (DIN), LED59.2 (DOUT)
unnamed: LED59.3 (DIN), LED60.2 (DOUT)
unnamed: LED60.3 (DIN), LED61.2 (DOUT)
unnamed: LED61.3 (DIN), LED62.2 (DOUT)
unnamed: LED62.3 (DIN), LED63.2 (DOUT)
unnamed: LED64.2 (DOUT), LED65.3 (DIN)
unnamed: LED65.2 (DOUT), LED66.3 (DIN)
unnamed: LED66.2 (DOUT), LED67.3 (DIN)
unnamed: LED67.2 (DOUT), LED68.3 (DIN)
unnamed: LED68.2 (DOUT), LED69.3 (DIN)
unnamed: LED69.2 (DOUT), LED70.3 (DIN)
unnamed: LED70.2 (DOUT), LED71.3 (DIN)
unnamed: LED71.2 (DOUT), LED72.3 (DIN)
unnamed: LED72.2 (DOUT), LED73.3 (DIN)
unnamed: LED73.2 (DOUT), LED74.3 (DIN)
unnamed: LED74.2 (DOUT), LED75.3 (DIN)
unnamed: LED75.2 (DOUT), LED76.3 (DIN)
unnamed: LED76.2 (DOUT), LED87.3 (DIN)
unnamed: LED77.3 (DIN), LED78.2 (DOUT)
unnamed: LED78.3 (DIN), LED79.2 (DOUT)
unnamed: LED79.3 (DIN), LED80.2 (DOUT)
unnamed: LED80.3 (DIN), LED81.2 (DOUT)
unnamed: LED81.3 (DIN), LED82.2 (DOUT)
unnamed: LED82.3 (DIN), LED83.2 (DOUT)
unnamed: LED83.3 (DIN), LED84.2 (DOUT)
unnamed: LED84.3 (DIN), LED85.2 (DOUT)
unnamed: LED85.3 (DIN), LED86.2 (DOUT)
unnamed: LED86.3 (DIN), LED87.2 (DOUT)
unnamed: U1.14 (D7_RX), U2.1 (B), U2.2 (A)
unnamed: C1.1, C10.2, C22.2, L2.1, U3.4 (OUT), U8.3 (IN)
unnamed: L2.2, U8.1 (SW)

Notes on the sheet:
LED63
connector for batt
LED control circuitry
western duplex matrix
LED50
EC11 Rotary Encoder w/ Switch
notes: - BAS16WS-BL for power diodes (C5264609)
LED34
devboard only supplies 5V when on USB
LED17
LED51
protection circuit won't do too much since it *only* helps with the LEDs but figured why not, just a couple more components
LED87
LED76
DIN must be >=0.7*VDD to be high 3.3 < 0.7*5, hence level shifter
LED77
LED33
5V boost conversion
SSD1306 OLED
LED64

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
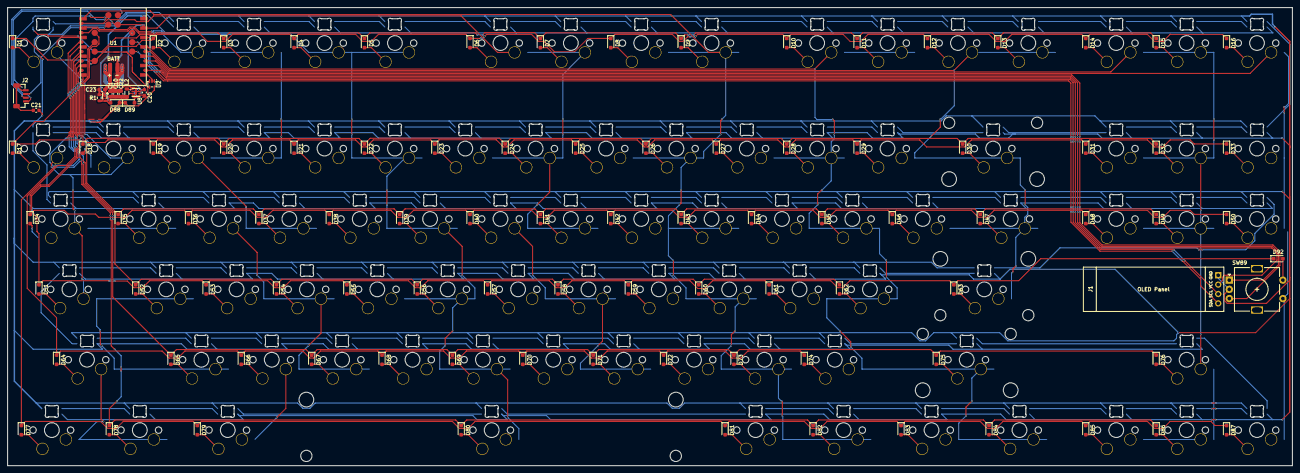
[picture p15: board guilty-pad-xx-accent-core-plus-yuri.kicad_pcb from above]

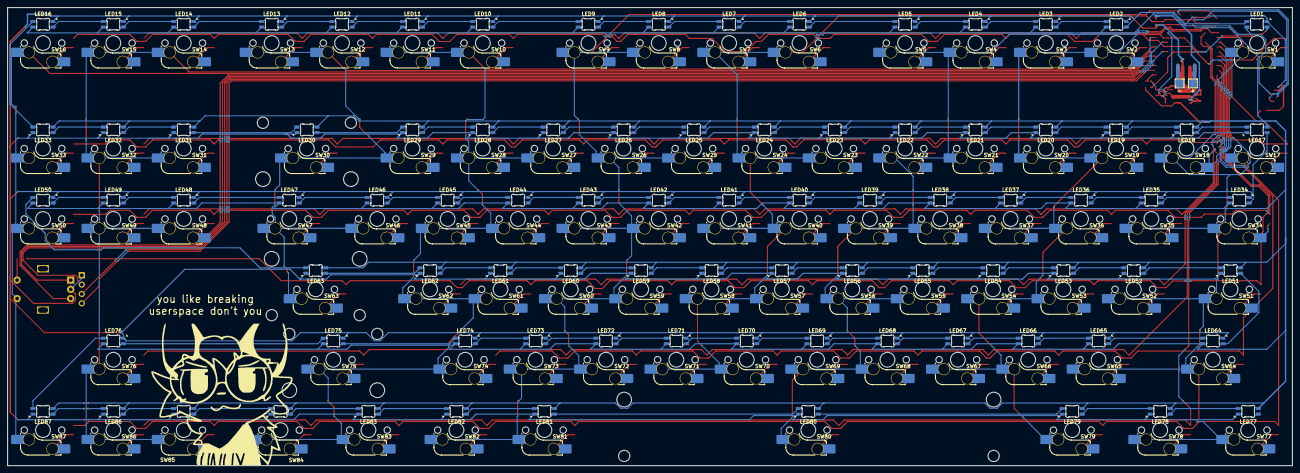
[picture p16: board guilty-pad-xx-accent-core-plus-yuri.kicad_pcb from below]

Board: 2 copper layers, 347.8 x 124.0 mm, 281 parts (176 on the bottom side), 213 nets.

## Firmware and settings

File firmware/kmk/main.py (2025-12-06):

import board
import busio
import digitalio
from kmk.kmk_keyboard import KMKKeyboard
from kmk.scanners import DiodeOrientation
from kmk.matrix import MatrixScanner
from kmk.keys import KC

# [AW9523B driver classes from previous example]
# ... (include the AW9523B and AW9523BPin classes here)

# Set up I2C and expander
i2c = busio.I2C(board.SCL, board.SDA)
aw = AW9523B(i2c, address=0x58)

# Mix expander pins and native board pins
# Example: columns use expander, rows use native GPIO
col_pins = [
    aw.get_pin(9),
    aw.get_pin(10),
    aw.get_pin(11),
    aw.get_pin(12),
    aw.get_pin(13),
    aw.get_pin(14),
    aw.get_pin(15),
    board.GP10,
    board.GP9,
    board.GP8,
]

row_pins = [
    aw.get_pin(0),
    aw.get_pin(1),
    aw.get_pin(2),
    aw.get_pin(3),
    aw.get_pin(4),
    aw.get_pin(5),
    aw.get_pin(6),
    aw.get_pin(7),
    aw.get_pin(8),
]

# Configure expander pins
for i, pin in enumerate(col_pins):
    if hasattr(pin, 'aw9523'):  # It's an expander pin
        pin.direction = digitalio.Direction.OUTPUT
        pin.value = True
    else:  # It's a native board pin
        native_pin = digitalio.DigitalInOut(pin)
        native_pin.direction = digitalio.Direction.OUTPUT
        native_pin.value = True
        col_pins[i] = native_pin

# Configure native row pins
for i, pin in enumerate(row_pins):
    native_pin = digitalio.DigitalInOut(pin)
    native_pin.direction = digitalio.Direction.INPUT
    native_pin.pull = digitalio.Pull.DOWN
    row_pins[i] = native_pin

# Initialize keyboard
keyboard = KMKKeyboard()
keyboard.matrix = MatrixScanner(
    cols=col_pins,
    rows=row_pins,
    diode_orientation=DiodeOrientation.COL2ROW
)

# TODO: actually do the keymap
# my god why didn't i just use a 24-pin thing and done a sensible matrix layout this would've been so much easier
keyboard.keymap = [
    [KC.A, KC.B, KC.C, KC.D, KC.E, KC.F, KC.G, KC.H]
]

if __name__ == '__main__':
    keyboard.go()

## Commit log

2025-11-30 schematic's just about done aside from rotary encoder
    [guilty-pad-xx-accent-core-plus-yuri.kicad_pcb, guilty-pad-xx-accent-core-plus-yuri.kicad_sch, leds.kicad_sch]
2025-12-03 schematic and pcb are done, images for those are added
    [Kailh Polia.step, LED_SK6812MINI-E.step, SSD1306_OLED-0.91-128x32.step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]
2025-12-04 update readme and add bom
    [BOM.csv, guilty-pad-xx-accent-core-plus-yuri.kicad_pcb]
2025-12-05 update README/BOM, use 4.7k resistors for i2c pullup
    [BOM.csv, guilty-pad-xx-accent-core-plus-yuri.kicad_pcb, guilty-pad-xx-accent-core-plus-yuri.kicad_sch]
2025-12-06 fix BOM
    [BOM.csv]
2025-12-06 no real schematic changes, just fix an old comment
    [guilty-pad-xx-accent-core-plus-yuri.kicad_sch]
2025-12-06 add case and update readme with it
    [case-bottom.f3d, case-middle.f3d, case-top.f3d]
2025-12-06 move kicad stuff to PCB folder
    [guilty-pad-xx-accent-core-plus-yuri.kicad_pcb, guilty-pad-xx-accent-core-plus-yuri.kicad_sch, leds.kicad_sch]
2025-12-07 add case in step format
    [case-bottom.step, case-middle.step, case-top.step]
2025-12-07 move 3d-models to pcb dir
    [Kailh Polia.step, LED_SK6812MINI-E.step, SSD1306_OLED-0.91-128x32.step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]
2025-12-08 add gerber.zip
2025-12-20 clean up tracks/vias
    [guilty-pad-xx-accent-core-plus-yuri.kicad_pcb]
2026-01-09 update with hotswap and stuff idek
    [BOM.xlsx]
2026-09-01 cleanup and add xrd to schematic, route LED data zigzag-y
    [guilty-pad-xx-accent-core-plus-yuri.kicad_sch, leds.kicad_sch]
2026-09-02 progress idk. western duplex matrix. stuff.
    [guilty-pad-xx-accent-core-plus-yuri.kicad_pcb, guilty-pad-xx-accent-core-plus-yuri.kicad_sch, leds.kicad_sch]
2026-09-03 finish schematic and routing
    [guilty-pad-xx-accent-core-plus-yuri.kicad_pcb, guilty-pad-xx-accent-core-plus-yuri.kicad_sch]
2026-09-03 update with fixed xrd footprint, fix oled pinout, fix some silkscreen stuff, idk what else
    [guilty-pad-xx-accent-core-plus-yuri.kicad_pcb, guilty-pad-xx-accent-core-plus-yuri.kicad_sch]
2026-09-04 update silkscreening
    [guilty-pad-xx-accent-core-plus-yuri.kicad_pcb]
2026-09-04 round corners
    [guilty-pad-xx-accent-core-plus-yuri.kicad_pcb]
2026-09-04 fix missing gnd for sip32408
    [guilty-pad-xx-accent-core-plus-yuri.kicad_pcb]
